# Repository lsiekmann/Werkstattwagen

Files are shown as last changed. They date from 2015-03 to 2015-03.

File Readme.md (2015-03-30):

## HELMER Werkzeugwagen
### Ein fahrbarer Werkzeugwagen mit zwei IKEA-HELMER Schubladenelementen

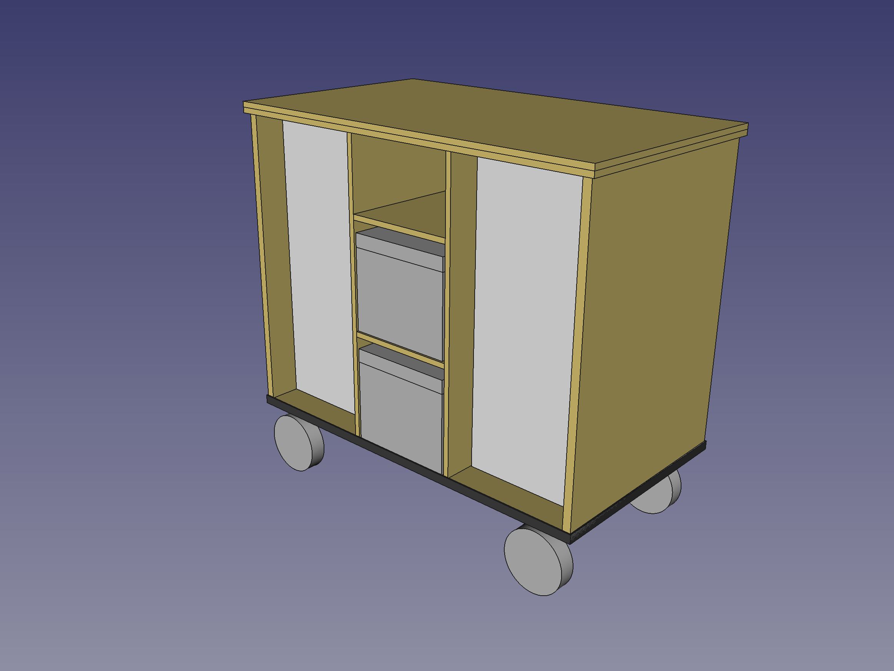
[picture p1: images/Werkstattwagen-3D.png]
3D-CAD-Modell


Der Korpus besteht aus 12 und 18 mm Birke-Multiplex und wird durch verleimte Flachdübel zusammengehalten.

Für ausreichend Stabilität beim Herumfahren sorgt ein Rahmen aus Stahlprofilen:
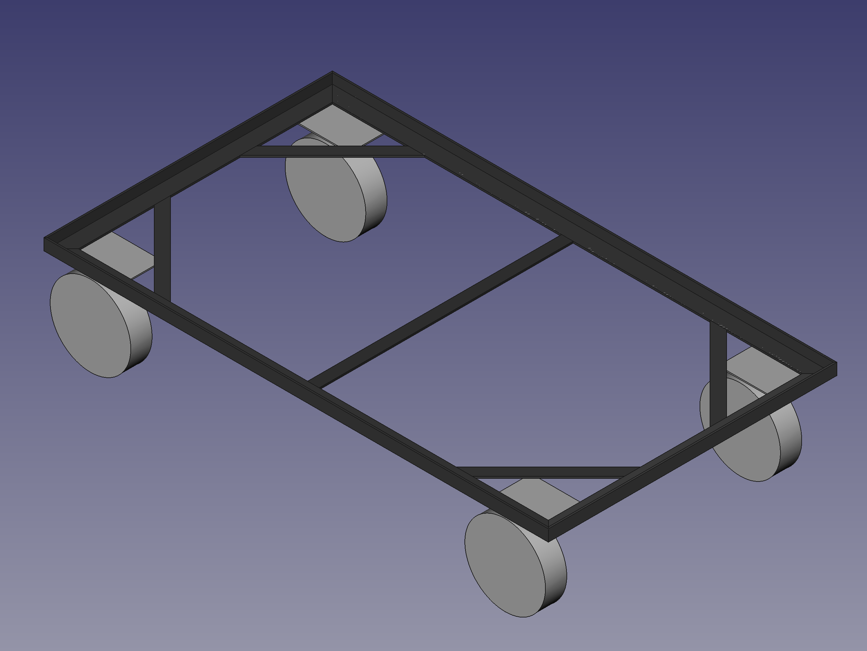
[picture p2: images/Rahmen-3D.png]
Stahlrahmen


Abmessungen: ca. 90 cm × 50 cm × 85 cm.

Die 2D-Zeichnungen (`*.dxf`) lassen sich z. B. mit [LibreCAD](http://librecad.org/) öffnen, das 3D-CAD-File (`*.fcstd`) mit [FreeCAD](http://www.freecadweb.org/).

#### Foto des fertigen Wagens:
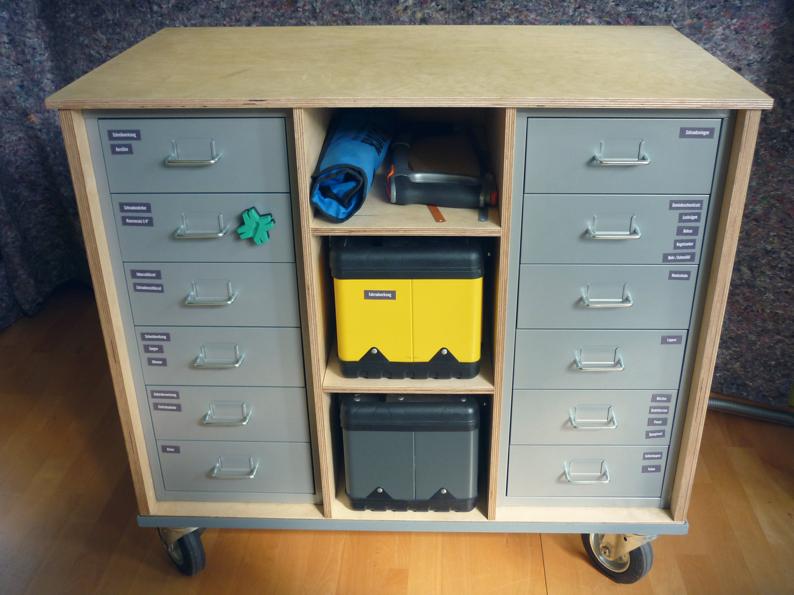
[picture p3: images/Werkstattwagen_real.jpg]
Foto Werkzeugwagen


#### Lizenz
 
Dieses Werk ist lizenziert unter einer [Creative Commons Namensnennung - Weitergabe unter gleichen Bedingungen 4.0 International Lizenz](http://creativecommons.org/licenses/by-sa/4.0/).

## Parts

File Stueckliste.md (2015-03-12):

# HELMER-Werkstattwagen
## Stückliste

### Holz
#### Birke-Multiplex 12 mm
* 2 Stk. 660 mm × 483 mm (Trennwände innen)
* 1 Stk. 890 mm × 515 mm (Deckplatte; 2 Stk. für 24 mm Dicke)
* 1 Stk. 660 mm × 834 mm (Rückwand)
* 2 Stk. 246 mm × 483 mm (Regalböden)

#### Birke-Multiplex 18 mm
* 2 Stk. 660 mm × 495 mm (Seitenwände)
* 1 Stk. 870 mm × 495 mm (Bodenplatte)

### Stahl
* L-Profil 20 mm × 30 mm, 2754 mm + Zuschlag
* Flachstahl 20 mm × 3 mm, 1189 mm + Zuschlag

### Schrauben, Muttern
* 16 Stk. M6 × 16 Senkkopfschraube
* 16 Stk. M6 selbstsichernde Mutter
* 16 Stk. Unterlegscheibe M6
* 19 Stk. Spansplattenschraube 4 × 16 mm

### Sonstiges
* 2 Stk. HELMER Schubladenelement
* 4 Stk. Lenkrolle 140 mm (alternativ 125 mm)
* ca. 70 Stk. Flachdübel
* Holzleim
* Rostschutzlack für den Stahlrahmen
* Holzwachs, Lasur o. Ä. für den Holzkorpus

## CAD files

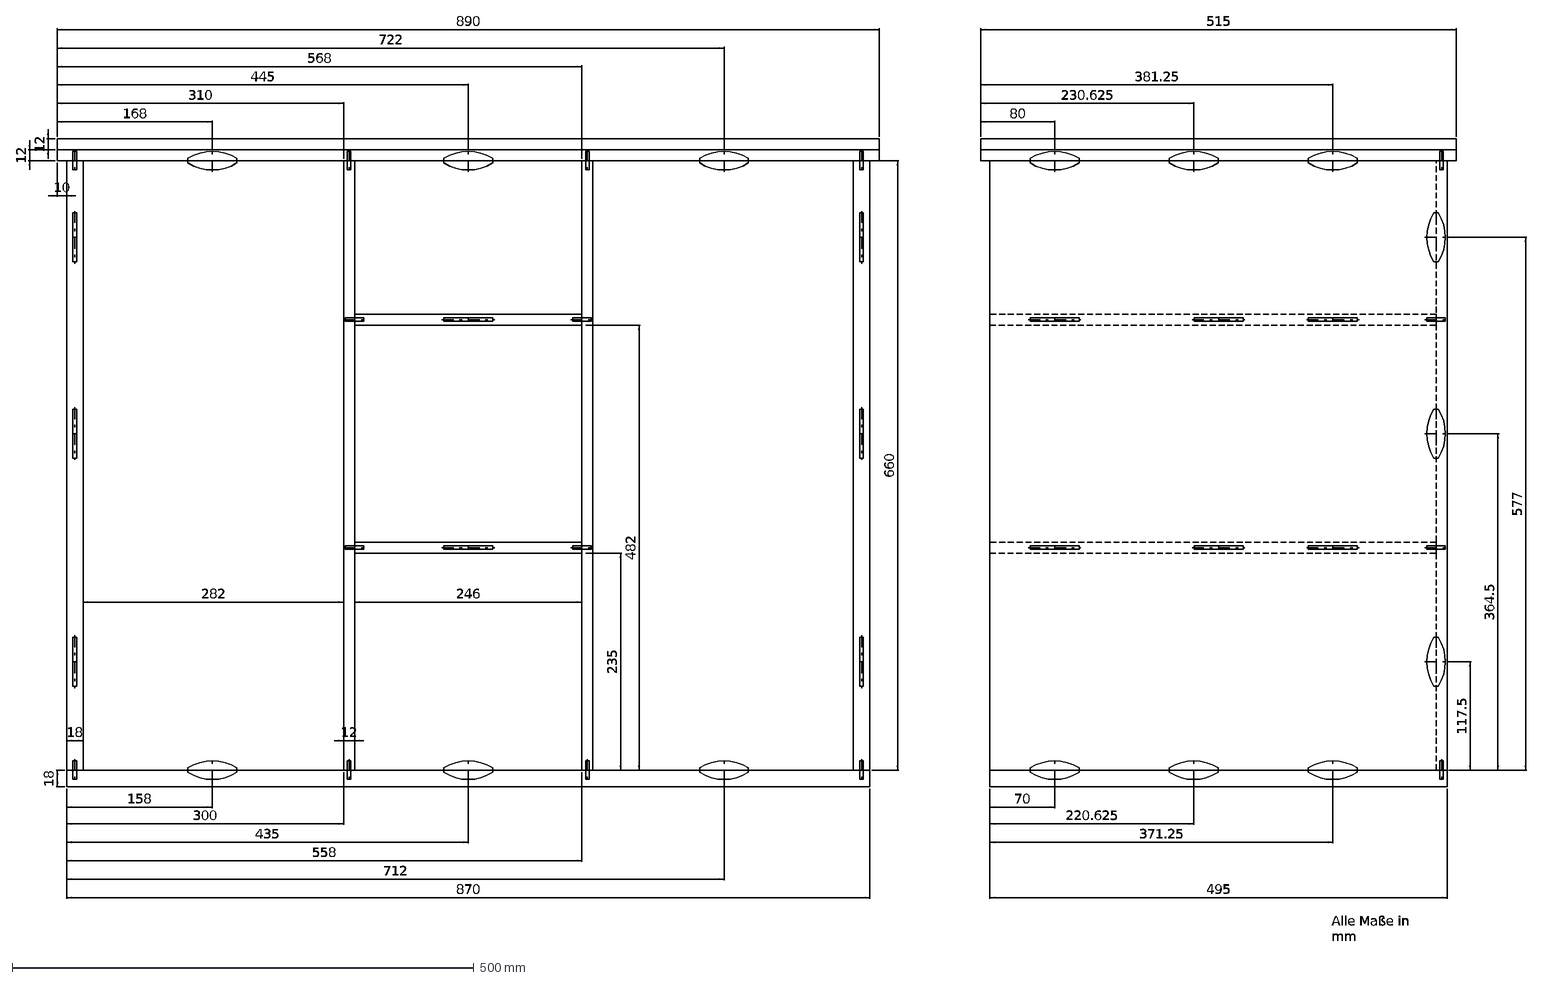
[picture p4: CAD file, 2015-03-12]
2D-CAD/Werkstattwagen-2D-Korpus.dxf
158
435
712
870
10
168
445
722
890
18
235
482
70
220.625
371.25
495
117.5
364.5
577
80
230.625
381.25
515
12
660
282
246
310
568
300
558
Alle Maße in mm

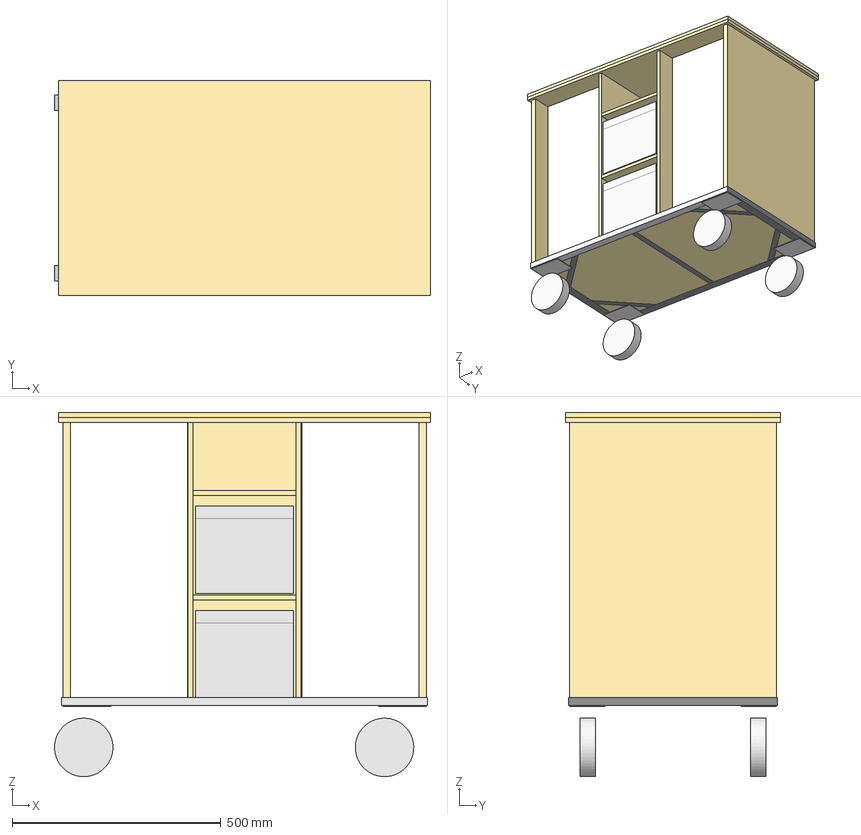
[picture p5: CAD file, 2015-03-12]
3D-CAD/Werkstattwagen-3D.fcstd
900.0 x 515.0 x 872.0 mm
Werkzeugkiste
Werkzeugkiste001
Bodenplatte
SeitenwandLinks
TrennwandLinks
TrennwandRechts
SeitenwandRechts
Rueckwand
HelmerLinks
HelmerRechts
RegalbodenUnten
RegalbodenOben
Rad1
Rad2
Rad3
Rad4
Deckplatte1cmU
Deckplatte1cmO
Rahmen1
Rahmen2
Rahmen3
Rahmen4
Querstrebe
RadPlatte1
RadPlatte2
RadPatte3
RadPlatte4
Winkelstrebe1
Winkelstrebe002
Winkelstrebe002 (Mirror #5)
Winkelstrebe004 (Mirror #4)001 (Mirror #5)001
Winkelstrebe003 (Mirror #3)001
Rahmen005 (Solid)
Rahmen006 (Solid)
Rahmen007 (Solid)
Rahmen008 (Solid)

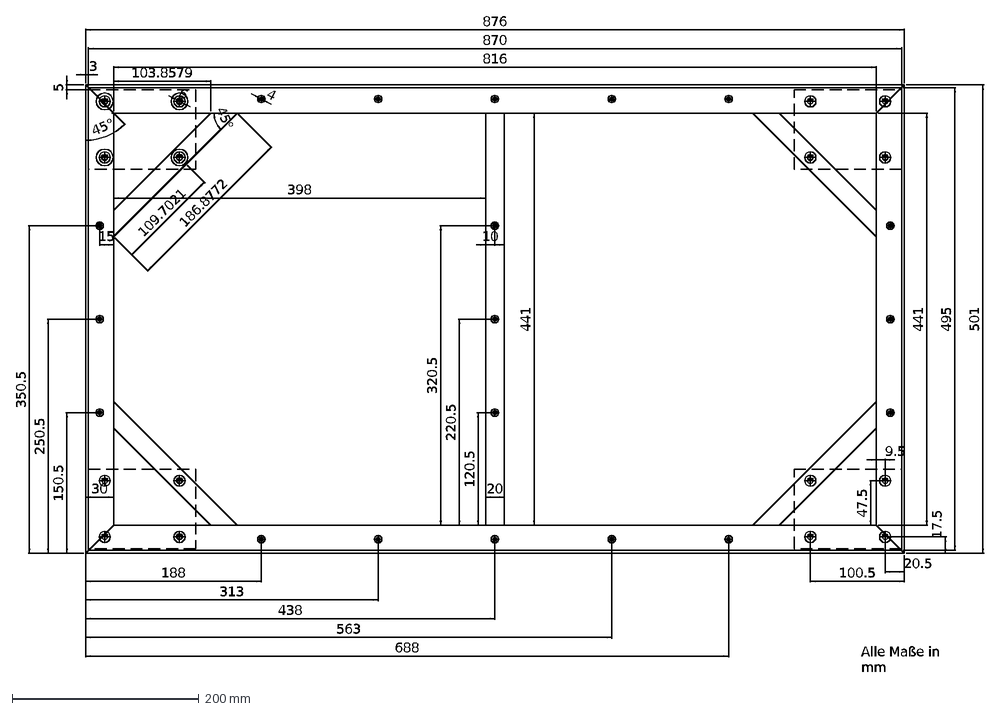
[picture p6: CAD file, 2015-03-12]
2D-CAD/Werkstattwagen-2D-Rahmen.dxf
441
20
30
15
10
150.5
250.5
350.5
120.5
220.5
320.5
188
313
438
563
688
816
4
45°
398
5
186.8772
109.7021
103.8579
6
20.5
100.5
17.5
47.5
9.5
3
495
501
870
876
Alle Maße in mm

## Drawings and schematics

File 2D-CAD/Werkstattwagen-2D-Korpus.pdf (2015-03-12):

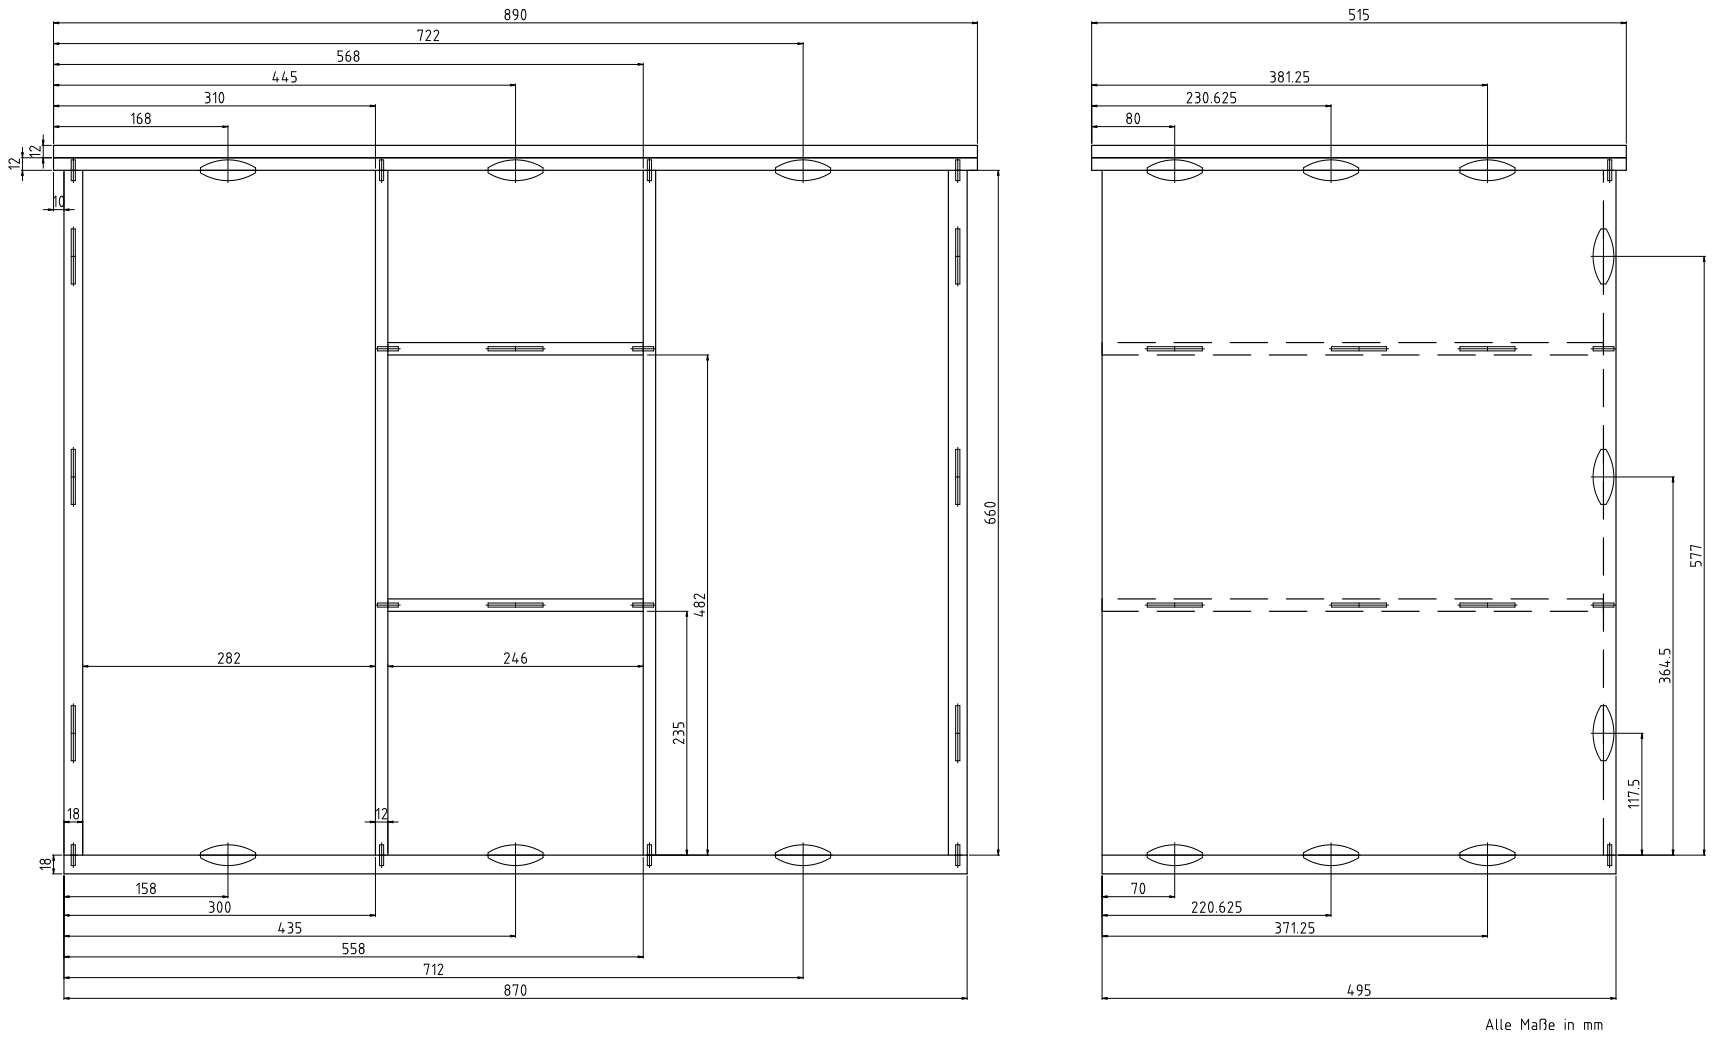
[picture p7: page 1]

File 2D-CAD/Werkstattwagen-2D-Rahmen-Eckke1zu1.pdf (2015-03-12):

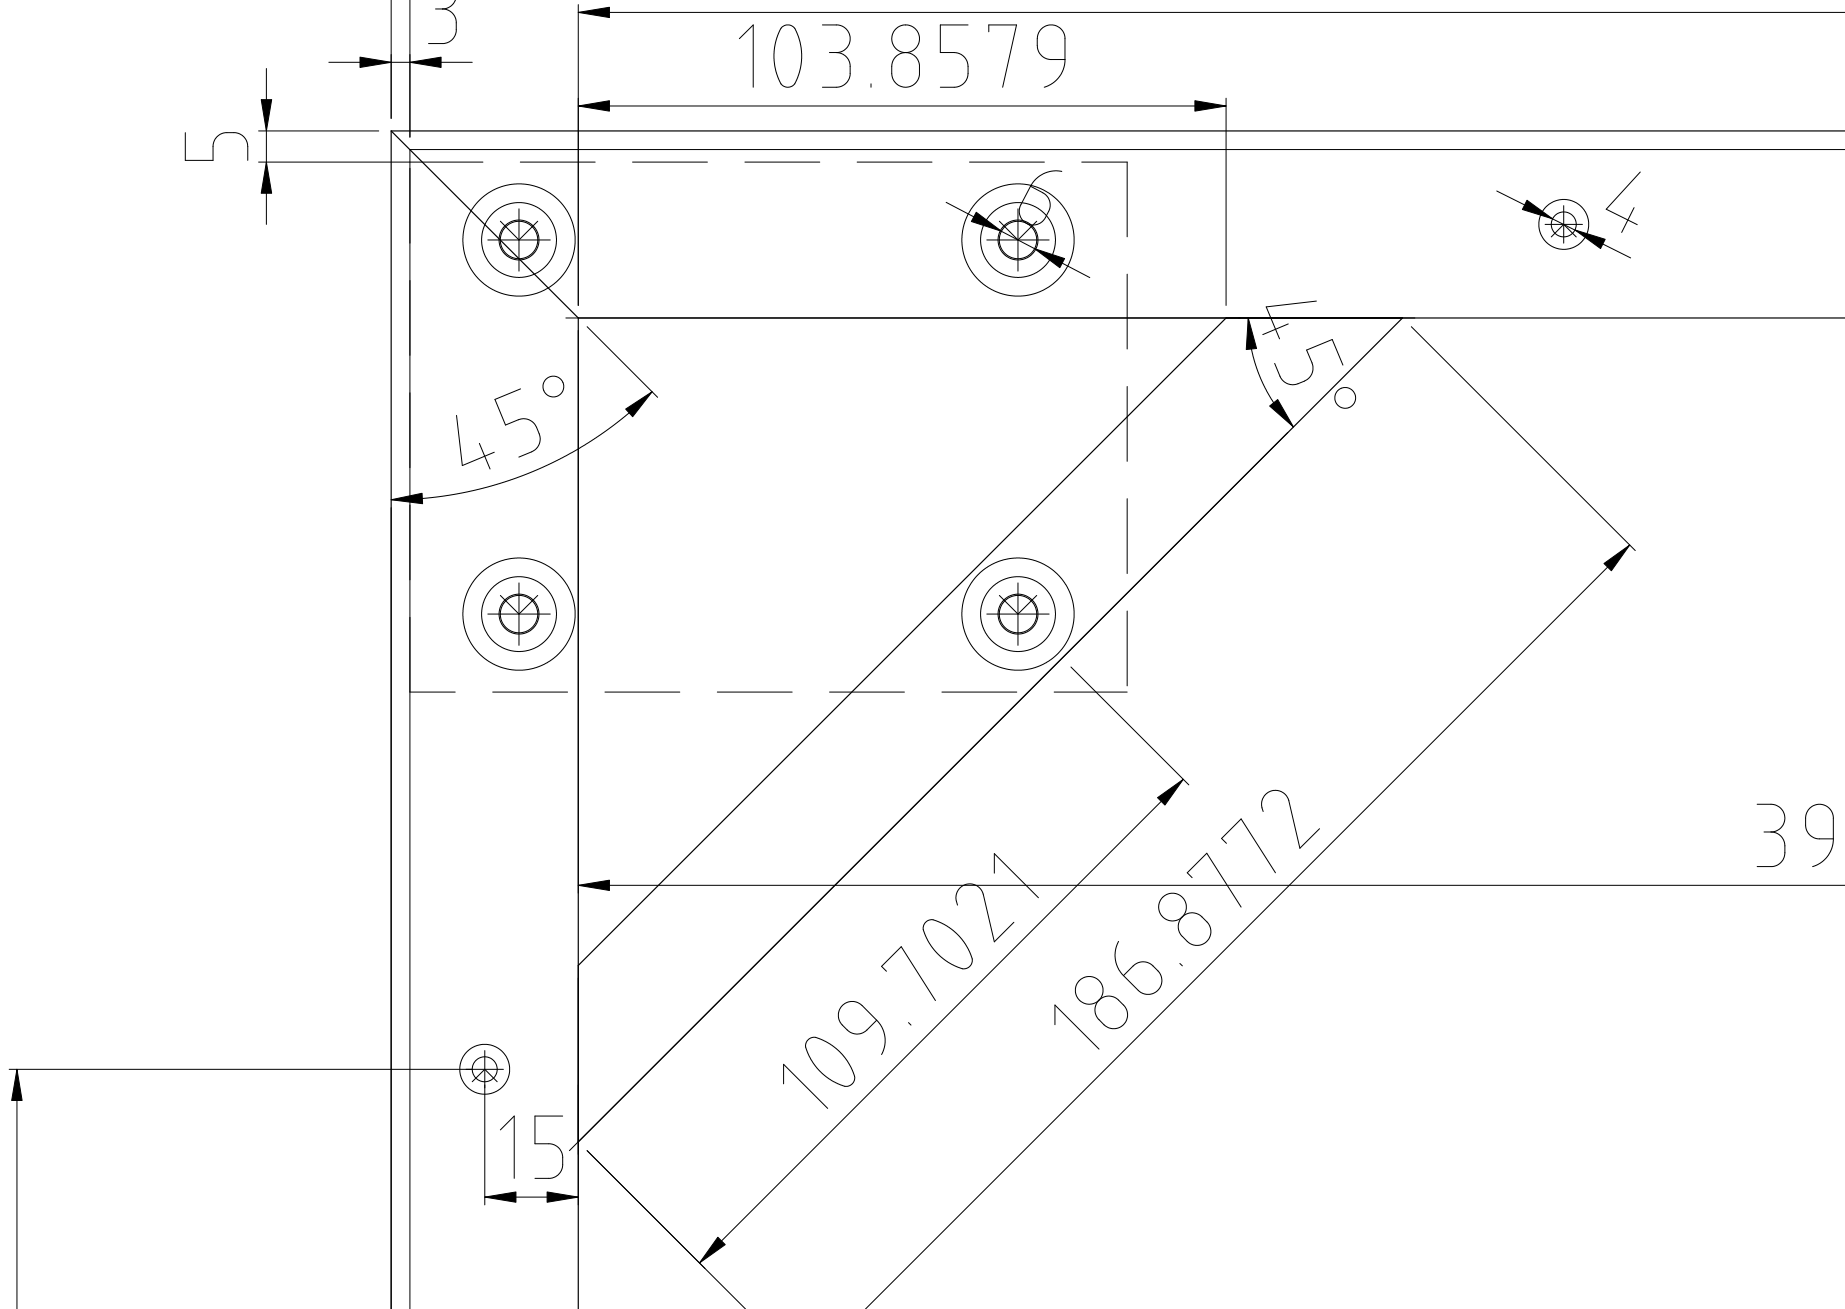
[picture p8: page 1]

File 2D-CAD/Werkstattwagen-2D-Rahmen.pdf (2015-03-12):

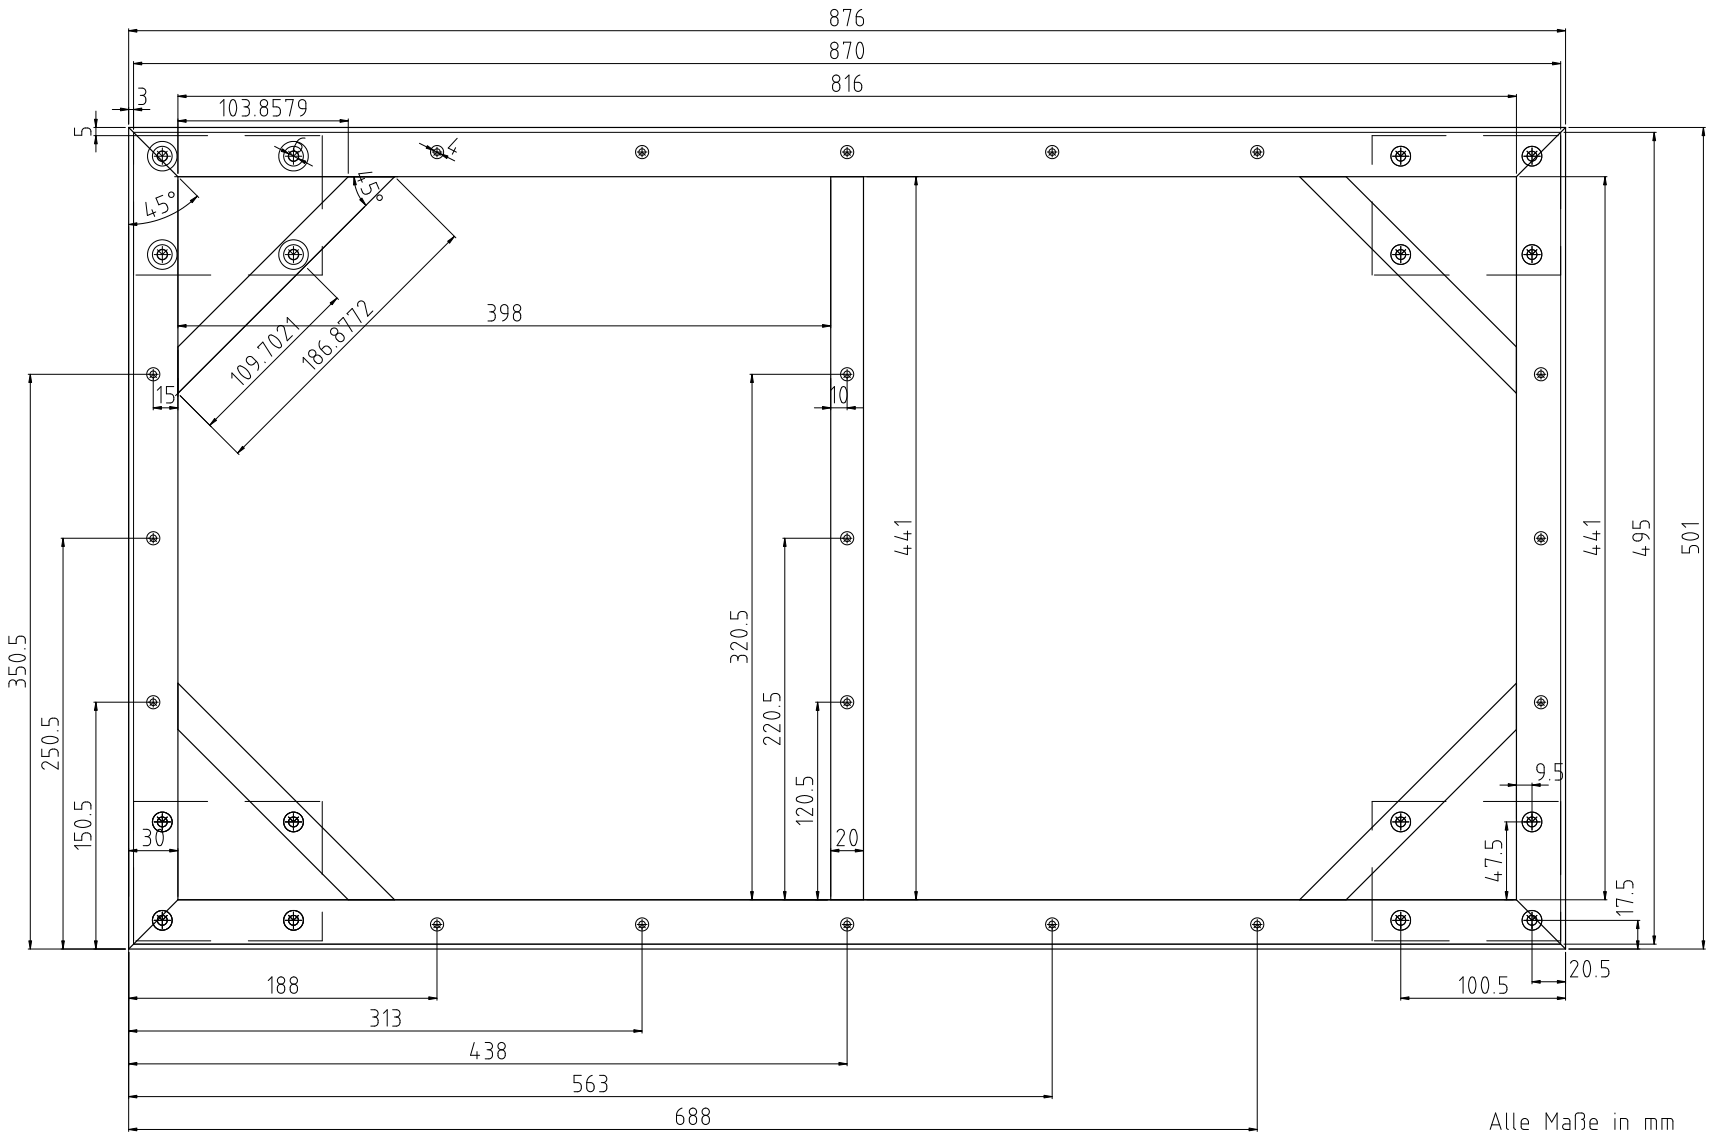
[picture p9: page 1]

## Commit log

2015-03-12 a bit more space for the HELMERs
    [Werkstattwagen-2D-Korpus.dxf, Werkstattwagen-3D.fcstd]
2015-03-12 add annotation about units of the dimensioning
    [Werkstattwagen-2D-Rahmen.dxf]
2015-03-12 add 2D plots of the frame as pdf
2015-03-12 remove ledger line from plot
    [Werkstattwagen-2D-Korpus.dxf]
2015-03-12 add bill of materials
2015-03-13 refactor file structure
    [Werkstattwagen-2D-Korpus.dxf, Werkstattwagen-2D-Rahmen.dxf, Werkstattwagen-3D.fcstd]

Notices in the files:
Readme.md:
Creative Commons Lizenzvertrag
